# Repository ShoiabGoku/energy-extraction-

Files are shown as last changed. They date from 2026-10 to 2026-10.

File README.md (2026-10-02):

# Energy extraction from electric eels, used for the right purposes

A machine design with **animated 3D models** that open in any 3D program, plus the engineering behind them.

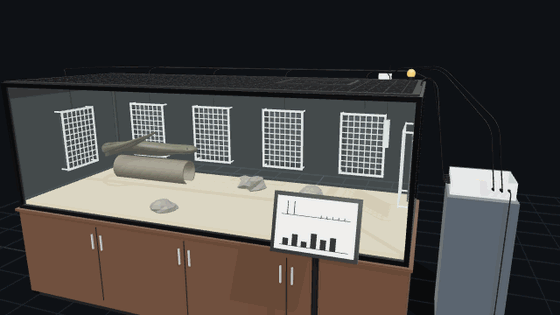
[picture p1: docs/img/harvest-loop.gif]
The eel swims, strikes its food, and the energy flows from two wall plates into the harvester


An electric eel can fire up to **860 V**, but each pulse lasts only about **2 ms**. Wall electrodes in its tank collect about **0.1 J a day**, so one eel would need about a thousand years to charge a phone. Taking more would mean provoking the animal, and that is cruel. The design therefore has two parts:

| | Part A: passive habitat harvester | Part B: artificial electric organ |
|---|---|---|
| Idea | Collect only the pulses the eel fires anyway | Copy the eel's cells in hydrogel instead of using the eel |
| Output | Microwatts, event-driven | Volts from salt gradients, scalable |
| Used for | Keeper shock alarm, eel health log, education display | Implants without battery-replacement surgery, soft robots, blue energy |
| Model | [`models/eel-habitat-harvester.*`](models) | [`models/artificial-electric-organ.*`](models) |

Read the full design, with the energy derivations, electronics, bill of materials, welfare rules and references, in **[docs/DESIGN.md](docs/DESIGN.md)**.

System diagram

## What the animation shows

The habitat model holds one **28.8-second loop** that packs a day's highlights together. The eel swims a path around the tank. Its body follows its head, it ripples with a travelling wave, and it rises to gulp air, as electric eels must. At three moments it fires, and each discharge is computed, not just drawn:

| Time | What the eel does | Plates that conduct | ΔV between them | Energy collected per pulse |
|---|---|---|---|---|
| 1.8 s | Probing doublet over the hide (2 pulses) | E2 + / E6 − | 26 V | 1.3 mJ |
| 7.7 s | Feeding strike: 70-pulse volley in two bursts | E5 + / E2 − | 71 V | 10.2 mJ |
| 27.1 s | Probing doublet near the end wall (2 pulses) | E1 + / E6 − | 51 V | 5.2 mJ |

The weak ~10 V sensing pulses it fires while cruising give only 0.7 V at the plates. That is below the bridge's 1.4 V diode drop, so they can't be harvested at all.

For every discharge you can watch the energy's path:

1. The **field lines** flash from the eel's head (+) to its tail (−).
2. The **conducting pair of plates** glows: red for +, blue for −.
3. **Energy dots** run along the two live leads into the harvester. Real current is instant; the dots are slowed so you can follow them.
4. The **bridge, catch capacitor, converter and supercapacitor** light up in turn.
5. The **alarm beacon** flashes, the **monitor LED** logs the event, and after the feeding strike the **e-paper display** refreshes with the new waveform.

The physics behind each frame comes from the same code that builds the model. The eel is treated as a head/tail current dipole in water of conductivity 0.01 S/m, and the six insulating tank walls are modelled as mirrors (the method of images). That gives each plate's voltage and, from those, the matched-load energy. All of it is saved in [`models/eel-habitat-harvester.timeline.json`](models/eel-habitat-harvester.timeline.json).

Part B animates too: Na⁺ ions cross the cation membrane one way and Cl⁻ ions cross the anion membrane the other way, together making one current.

## The viewer and its panels

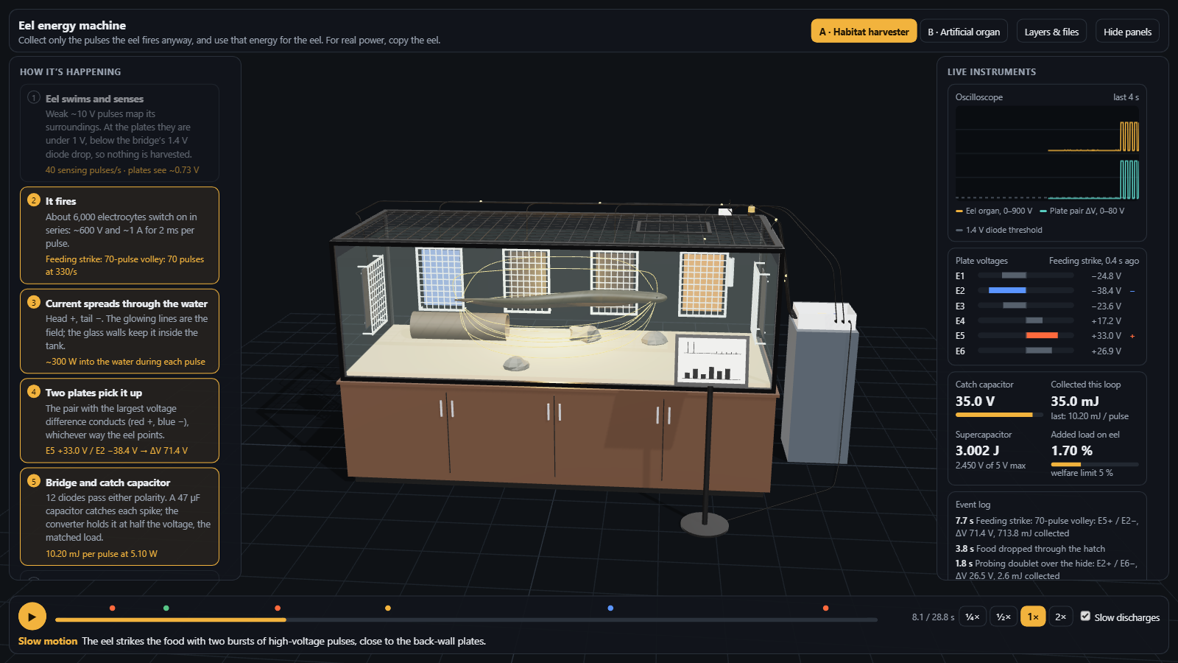
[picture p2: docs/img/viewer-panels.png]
Viewer with the step and instrument panels during the feeding strike


Open `index.html` through any static server, or enable GitHub Pages for this repo. The viewer has:

- **How it's happening.** Seven steps, from "Eel swims and senses" to "Put to the right use". Each one lights up while it is happening, with live numbers such as the conducting plates, ΔV, energy per pulse and energy stored.
- **Live instruments.** An oscilloscope of the eel's voltage and the plate-pair ΔV against the 1.4 V diode threshold. Voltage bars for all six plates with the + and − pair marked. Gauges for the catch capacitor and supercapacitor, the energy collected this loop, and the added load on the eel against the 5% welfare limit. An event log.
- **Transport.** Play/pause, a scrubber with event markers, speeds from ¼× to 2×, and automatic slow motion during discharges. A caption narrates what is happening.
- **Part B panels.** A five-step explanation of the gel battery and a stack calculator: drag the number of cells and see the voltage and stack length.
- **Hover any part** to read its description. Use **Layers & files** to toggle parts and download any format.

## 3D models

Each model is exported in three formats so that anything can open it:

| File | Format | Opens in | Notes |
|---|---|---|---|
| `*.glb` | glTF 2.0 binary, **animated** | Blender, Unity, Unreal, Godot, three.js / Babylon.js, Windows 3D Viewer, KeyShot, online glTF viewers | Rigged eel (24-joint skin) and one looping clip with 100 channels: swimming, field flashes, plate glows, energy dots, harvester stages, beacon, display, food. PBR materials, named hierarchy, a description on every part (`extras.description`). Passes the Khronos glTF Validator with 0 errors, 0 warnings, 0 hints |
| `*.obj` + `*.mtl` | Wavefront OBJ | Practically every 3D program: Maya, 3ds Max, Cinema 4D, SketchUp, Rhino, MeshLab… | One frozen moment, mid feeding strike. One named object per part with colours, emission and opacity |
| `*.stl` | Binary STL | Slicers (Cura, PrusaSlicer), CAD (Fusion, SolidWorks, FreeCAD), and **GitHub's built-in 3D preview** (click the file) | The same frozen moment. Single colour, **millimetres, +Z up**, opaque parts only (glass, water, field lines and glows left out so you can see inside) |

GLB and OBJ use **metres, +Y up**. The habitat model is 3.7 × 1.9 × 1.9 m including the pedestal and display. The organ model is 380 × 200 × 87 mm. In renderers that don't play animation, the GLB shows the same frozen moment as the OBJ.

| Eel and its discharge field | Energy reaching the harvester |
|---|---|
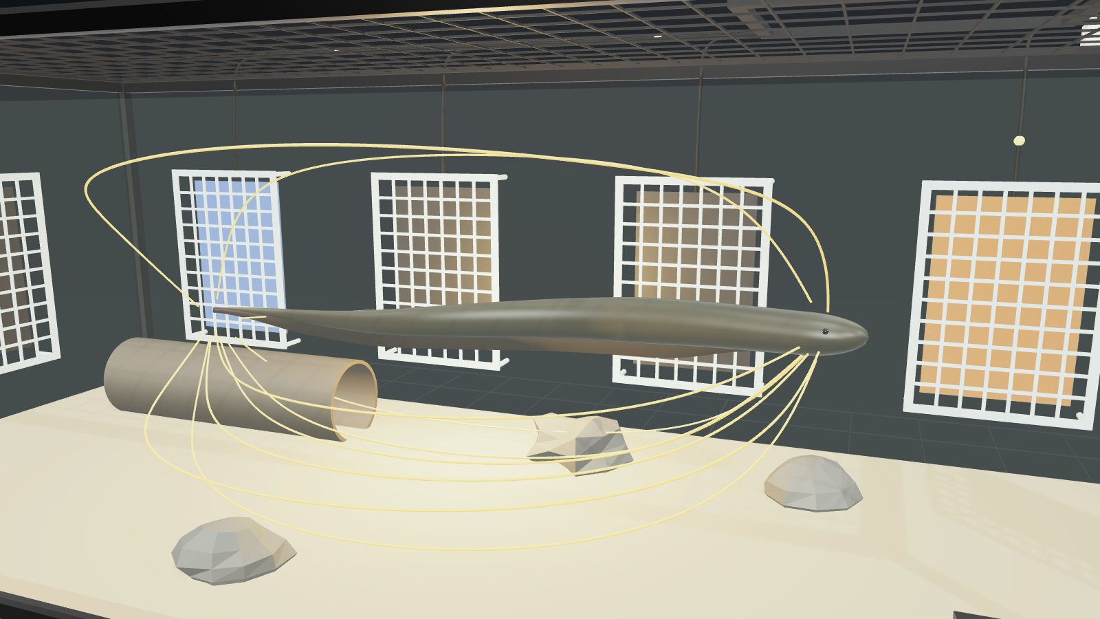
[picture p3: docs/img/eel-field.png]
Eel and discharge field
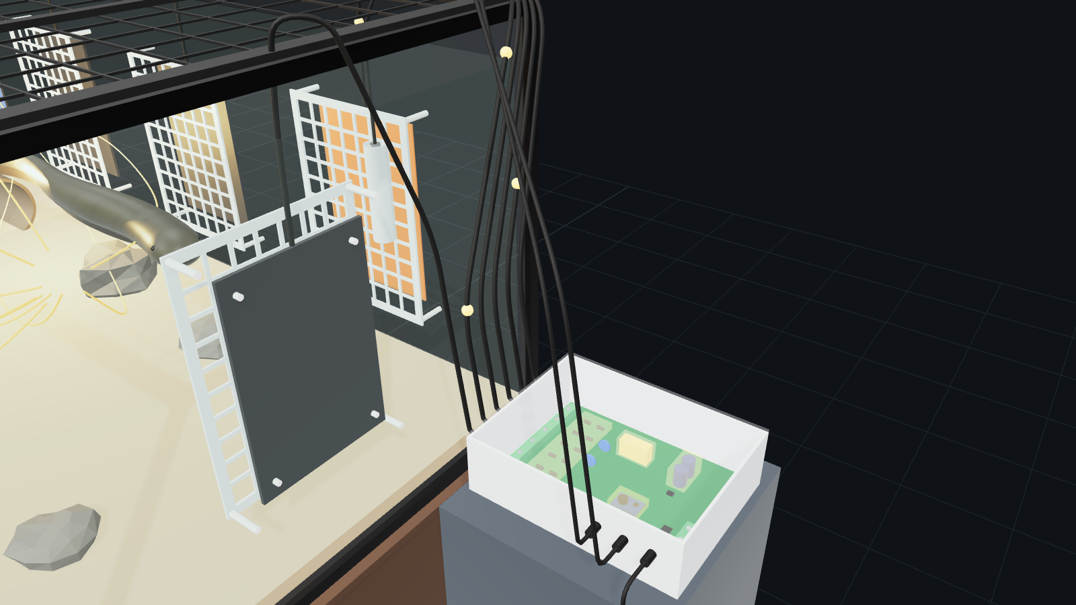
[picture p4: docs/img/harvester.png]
Harvester electronics
|  |  |
| **Whole habitat** | **Part B: artificial electric organ** |
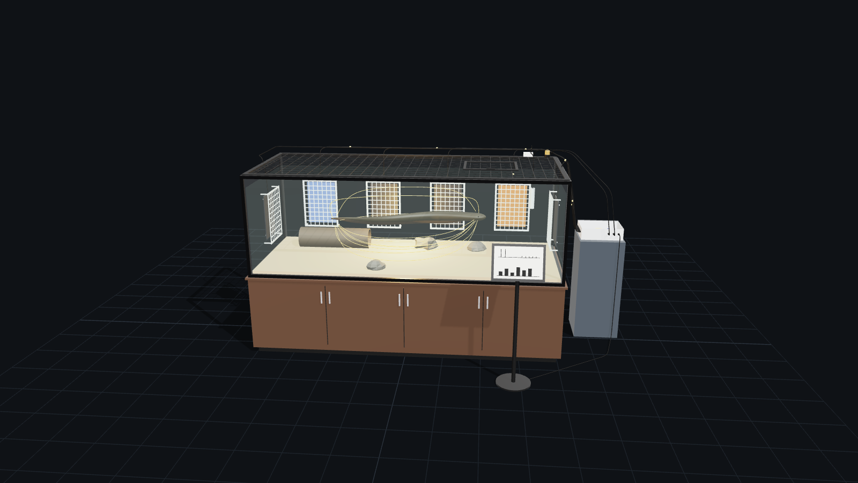
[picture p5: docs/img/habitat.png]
Habitat
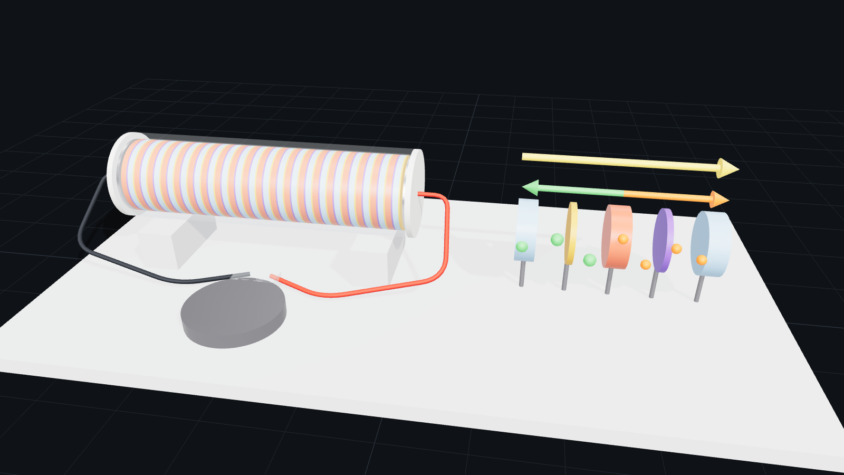
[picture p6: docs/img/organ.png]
Organ
|  |  |

### Quick start

- **Blender:** File → Import → glTF 2.0 → `models/eel-habitat-harvester.glb`, then press play in the Timeline. The water and glass are transparent; the field lines, plate glows and beacon glow.
- **Windows:** double-click the `.glb` file. 3D Viewer plays the animation.
- **Unity / Unreal / Godot:** import the `.glb` and play its one clip, "Swim and harvest (loop)".
- **Browser:** run `python -m http.server` in this folder and open `http://localhost:8000`.
- **Print or CAD:** use the `.stl` file.

## Regenerating the models

The models, the animation and the timeline are all generated from code. Every dimension, the swimming path and the electrical constants in [`tools/build_models.py`](tools/build_models.py) can be changed and rebuilt:

```bash
pip install numpy
python tools/build_models.py
```

The output is deterministic, so the same code always produces the same files.

## The rules built into this machine

1. **Passive only.** No prodding, baiting, stimulation, or feeding schedules changed to make the eel fire more.
2. **No added effort for the eel.** The harvester may add at most 5% to the eel's load. It adds about 0.1–0.5% mid-tank and up to ~2% when the eel fires right beside a plate.
3. **Welfare comes before output.** The health monitor runs on its own battery, so it never goes dark when a sick eel discharges less.
4. **No surgery, implants or restraint.** Only captive-bred or rescued eels in accredited facilities.
5. **No weapons or stunning devices.** The 3.3 V-only output and small energy store make that a hardware limit.

Energy figures are order-of-magnitude estimates with their assumptions stated in [DESIGN.md](docs/DESIGN.md). They should be refined with measurements from a real habitat.

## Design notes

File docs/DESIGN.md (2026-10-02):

# Design: an electric-eel energy machine used for the right purposes

This document is the engineering design behind the 3D models in [`../models`](../models).
It has two parts:

- **Part A, the passive habitat harvester.** It collects a small share of the pulses an electric eel fires anyway, and spends that energy on keeper safety and teaching. It never stimulates the animal.
- **Part B, the artificial electric organ.** It copies the eel's electrocytes in hydrogel. This is the only route to useful amounts of power, and it needs no animal.

The numbers below are estimates accurate to about a factor of ten. Each one shows its assumption so it can be checked against real measurements.

---

## 1. The constraint that shapes everything

An electric eel's discharge is powerful but brief. One high-voltage pulse reaches hundreds of volts, but lasts only about 2 ms. Most of its energy heats the water right next to the eel. Getting a lot of energy out of an eel would mean provoking it to fire again and again. That is cruel, and the arithmetic below shows it still wouldn't give useful power.

So the design rule is: **collect passively, spend the energy on the eel's keepers and visitors, and get real power from biomimicry (copying how the eel works), not from the animal.**

## 2. The source

| Property | Value | Source / note |
|---|---|---|
| Electrocytes | ~6,000 in series, ~0.15 V each | Cells stacked along the body, like batteries in a torch |
| Peak organ voltage | up to 860 V (*E. voltai*); ~500–600 V other species | de Santana et al., 2019 |
| Pulse width | ~2 ms | High-voltage discharge |
| Volleys | up to ~400 pulses/s while hunting | Catania, 2014 |
| Polarity | head positive, tail negative | |
| Internal resistance, R_i | ~300 Ω (assumed) | To be measured during commissioning |

**Pulse energy.** Treat the eel as a voltage source V_e behind R_i, driving into the water.
The water's resistance between the head and tail regions is roughly that of two small electrodes in a large bath:

```
R_water ≈ (1 / 2πσ) · (1/a − 1/d)        a ≈ 0.05 m, d ≈ 1.5 m, σ ≈ 0.01 S/m (100 µS/cm)
        ≈ 300 Ω
I       ≈ V_e / (R_i + R_water) ≈ 600 / 600 ≈ 1 A
P_water ≈ I² · R_water ≈ 300 W   for ~2 ms   →   E_pulse ≈ 0.6 J   (range 0.1–1 J)
```

## 3. What the wall plates can actually collect

Away from the eel, the water carries the potential field of a current dipole:

```
φ(r) = (I / 4πσ) · (1/r₊ − 1/r₋)          I / 4πσ ≈ 8 V·m
```

With the eel mid-tank, a back-wall plate sits about 0.6 m from the head and 1.5 m from the tail.
The insulating glass walls roughly double the potential, since current can't leave the water.
Typical plate-to-plate differences come out at **10–30 V**. They are higher when the eel swims right past a plate.

Each 300 × 450 mm plate has a spreading resistance into the water of about 1/(4σa) ≈ 120 Ω, where a ≈ 0.21 m is the plate's equivalent radius. A pair therefore looks like a ~20 V source behind ~240 Ω. Even with a perfectly matched load:

```
P_harvest = ΔV² / 4R ≈ 20² / 960 ≈ 0.4 W   for 2 ms   →   ≈ 1 mJ per pulse   (≈ 0.2–10 mJ)
```

That is about **0.1–1%** of what the eel puts into the water.

### Daily energy budget (one adult eel)

| Step | Typical | Range |
|---|---|---|
| High-voltage pulses per day in captivity (feeding volleys, startles, probing) | 200 | 50–1,000 |
| Energy collected per pulse | 1 mJ | 0.2–10 mJ |
| Converter efficiency (bursty, high-voltage input) | 70% | 60–75% |
| **Collected per day** | **~0.14 J** | ~0.01–7 J |
| **Average power** | **~1.6 µW** | ~0.1–80 µW |

For scale, a phone charge is about 15 Wh, or 54 kJ. At the typical rate, one eel would need **about a thousand years** to charge one phone.

> An earlier back-of-envelope version of this design assumed 1–5% capture. The dipole and spreading-resistance analysis above lowers that by roughly 10×. The design has been changed to match (see §4.5).

### Extra effort for the eel: negligible by design

Mid-tank, the harvester draws about 0.4–0.7 W, briefly, from a ~300 W pulse, so it adds about 0.1–0.2% to the eel's load. When the eel fires right beside a plate it can reach ~5 W, about 2%. The welfare rule (§5) caps this at 5%, and a commissioning test checks it (§4.7).

## 4. Part A: passive habitat harvester

Habitat harvester

### 4.1 Habitat (welfare comes first)

| Item | Spec |
|---|---|
| Tank | 3.0 × 1.2 × 1.0 m outside, 19 mm glass, about 2,900 L of water |
| Water | Soft and warm, at species-appropriate values set by the keeper or vet. Surface 12 cm below the rim: electric eels gulp air and must reach it |
| Lid | Escape-proof mesh with a feeding hatch |
| Furnishing | Dark hide tube (Ø220 mm), rocks, sand substrate |
| Stand | 0.8 m cabinet; mains equipment (heater, pump) on a 30 mA RCD/GFCI |

### 4.2 Electrode array

- **Six graphite plates,** 300 × 450 × 8 mm: one on each end wall (E1, E6) and four on the back wall (E2–E5), centred at mid-depth. Graphite is inert. Copper, zinc and brass are never used, because their ions are toxic to fish.
- **Guard screens:** perforated acrylic grids 75 mm from the glass, with ~40 mm openings, so the eel can never touch an electrode.
- **Wiring:** each plate has one silicone-insulated lead. The joint is potted in epoxy, so the only conductor touching the water is the graphite face.
- **Why six plates:** the eel's head-to-tail axis changes every time it turns. With six plates, some pair always lies roughly along that axis.

### 4.3 Pulse catcher

```
 E1 ─┬─▶|─┐                          ┌──────────────┐
     └─|◀─┼─┐      + rail ───┬───────┤ buck, MPPT   ├──▶ low-leakage supercap ──▶ 3.3 V loads
 E2 ─┬─▶|─┘ │                │       │ in 6–150 V   │
     └─|◀───┤   (×6 plates)  ═╪═ 47 µF  wake ≥ 10 V  │
  …         │                │ 250 V └──────────────┘
 E6 ─┬─▶|─  │      MOV+TVS ──┤ 150 V
     └─|◀───┴──── − rail ────┘
```

- **Six-input polyphase diode bridge** (12 diodes, ≥1 kV). Each plate has one diode to the + rail and one to the − rail. The rails therefore always carry the largest plate-to-plate difference, whatever the polarity and whichever two plates see it. No switching logic is needed.
- **Clamp:** a varistor (MOV) plus a TVS diode at ~150 V, for the rare pulse when the eel touches a guard right next to a plate.
- **Catch capacitor:** 47 µF / 250 V film. It smooths each 2 ms spike. Its time constant with the ~240 Ω plate source is about 11 ms, so charge builds up across a volley.
- **Converter:** a buck converter accepting 6–150 V input, ~5 W peak. A feeding volley fired beside a plate averages ~3.4 W for a fraction of a second; anything above the rating is shed by the clamp. It wakes when the capacitor reaches 10 V and then runs *fractional open-circuit MPPT* (maximum power point tracking): it holds its input at about half the open-circuit plate voltage. That is the matched load from §3 that extracts the most energy from each pulse. It sleeps again between volleys, drawing well under 1 µW.
- Note that the catch capacitor can never charge above the plate voltage. A start threshold set higher than typical pulses (10–30 V) would never fire, which is why the wake threshold is low.

### 4.4 Storage: the leakage trap

A good-quality 1 F supercapacitor at 5 V leaks a few microwatts on its own. That is about as much as the eel delivers on a typical day, so long-term storage would mostly store nothing. The design therefore **spends energy where it is caught:**

1. A volley charges the catch capacitor.
2. That charge flashes the alarm beacon directly and wakes the logger to record the event.
3. Only on unusually active days does the surplus top up the supercapacitor bank: 2 × 2 F / 2.7 V low-leakage cells in series, giving 1 F and 12.5 J at most. That bank feeds the display.
4. The output is **3.3 V only**, by hardware design, so it can never be turned into a shocking device.

### 4.5 Loads: the right purposes

| Load | What it does | Power | Powered by |
|---|---|---|---|
| **Keeper shock alarm** | Amber beacon on the lid by the feeding hatch flashes after every high-voltage volley | ~3 mJ per 50 ms flash, ~0.1 J per event | **The volley itself**, through the catch capacitor. The shock powers its own warning |
| **Eel health monitor** | Logs water temperature, conductivity and every discharge (count, amplitude, timing). Alerts keepers by Bluetooth LE | ~25 µW average | **Its own 10-year lithium cell**; harvested energy only tops it up |
| **Education display** | Large e-paper panel: energy collected today, the last pulse waveform, "years to charge a phone" | Holds its image at zero power; ~0.1–0.5 J per refresh | **Surplus only.** It refreshes when the eel has made enough, and the waiting is part of the lesson |

Two deliberate decisions:

- **The health monitor does not depend on the eel's energy.** A sick or stressed eel may discharge less, which is exactly when monitoring matters most. An eel-powered monitor would go dark at the worst moment.
- **Beacon on means the water is definitely live. Beacon off does not mean it is safe.** Keepers always follow the insulated-glove protocol.

**What the plates are best at is information, not energy.** The discharge record is a continuous, non-invasive behaviour log. Feeding strikes, probing doublets, startles, and long quiet periods (possible illness) all show up in it.

Monitor alert rules (starting points for the vet to tune):

- High-voltage volleys outside feeding times above a set hourly rate → possible stress.
- Discharge activity down more than 50% over 24 h → check health.
- Temperature or conductivity outside the set band → water-quality alert.

### 4.6 Bill of materials

| Qty | Part | Spec |
|---|---|---|
| 1 | Glass tank + cabinet + mesh lid | 3.0 × 1.2 × 1.0 m, 19 mm glass |
| 6 | Graphite electrode plates | 300 × 450 × 8 mm |
| 6 | Acrylic guard screens + PVC standoffs | 380 × 530 mm, 75 mm stand-off |
| 6 | Silicone-insulated leads, epoxy-potted joints | ~5 m each |
| 12 | Diodes | ≥1 kV, fast recovery |
| 1 | MOV + TVS clamp | ~150 V |
| 1 | Film capacitor | 47 µF / 250 V |
| 1 | High-voltage-input buck converter | hysteretic start, ~2 W |
| 2 | Supercapacitors, low leakage | 2 F / 2.7 V, in series |
| 1 | Low-power MCU + Bluetooth LE radio | |
| 1 | Temperature + conductivity probe, in a guard tube | |
| 1 | Lithium primary cell for the monitor | AA Li-SOCl₂ |
| 1 | Amber LED beacon | |
| 1 | Large e-paper display on a stand | |
| 1 | IP-rated enclosure with clear lid, 9 cable glands, steel pedestal | |

### 4.7 Commissioning tests

1. **Loading test (welfare).** With a separate high-impedance probe pair (≥10 MΩ), record the eel's pulse amplitude with the harvester connected and disconnected. The difference must be under 5%. If it isn't, add series resistance per plate or remove plates.
2. **No DC into the water.** With no eel present, measure the current through every plate lead. It must be zero within instrument resolution.
3. **Isolation.** The harvester floats: no connection to mains earth. Check insulation from every lead to the enclosure at 1 kV.
4. **Field calibration.** Log a week of plate voltages, then refine the energy budget in §3 with real numbers.

### 4.8 Simulated discharges (what the animation shows)

`tools/build_models.py` turns this section into numbers for every discharge in the animated model:

- **Eel.** A 1.65 m rig with 24 joints follows a closed swimming path at ~0.18 m/s. It speeds up to strike and slows to surface. A travelling body wave runs faster than the eel swims.
- **Field.** The eel is a current dipole: +1 A at the head end of the organ, −1 A at the tail, in water with σ = 0.01 S/m. The four glass walls, the floor and the water surface are insulating, so each source is mirrored in all six (first-order method of images).
- **Plates.** Each plate's voltage is the field's potential averaged over a 5 × 5 grid on its face. The bridge conducts the most-positive and most-negative plates. The energy per pulse is (ΔV − 1.4 V)² / (4 × 240 Ω) × 2 ms.

| Discharge | Eel position | Conducting pair | ΔV | Per pulse | Pulses | Collected | Added load |
|---|---|---|---|---|---|---|---|
| Probing doublet | over the hide, mid-tank | E2 + / E6 − | 26.5 V | 1.3 mJ | 2 | 2.6 mJ | 0.2% |
| Feeding strike | beside the back-wall plates | E5 + / E2 − | 71.4 V | 10.2 mJ | 70 | 714 mJ | 1.7% |
| Probing doublet | head near end wall E1 | E1 + / E6 − | 51.2 V | 5.2 mJ | 2 | 10.3 mJ | 0.9% |
| Sensing pulses (~10 V) | cruising | none | 0.7 V | 0 | — | 0 | 0% |

The table shows how much **position** matters. The same eel collects about 8× more per pulse when it fires beside a plate than when it fires mid-tank. A feeding strike right beside the plates, as in this example, is close to the best case. A typical day, with most pulses mid-tank, stays around 0.1 J. The animation also stretches each 2 ms pulse into a visible flash and slows the energy dots in the leads; the numbers above use the real timings.

## 5. Rules built into the machine

These are requirements the design must meet, not suggestions:

1. **Passive only.** No prodding, baiting, electrical stimulation, or feeding schedules changed to make the eel fire more. The machine never tries to increase its output.
2. **No added effort for the eel.** The harvester may add at most 5% to the eel's load (checked by test 4.7-1). Typically it adds ~0.1%.
3. **Welfare comes before output.** Discharge patterns that suggest stress raise an alert. Nothing in the system rewards "more energy".
4. **No surgery, implants or restraint.**
5. **Only captive-bred or rescued eels** in accredited facilities. No wild capture for energy.
6. **No weapons or stunning devices.** The low-voltage-only output and small energy store make this a hardware limit, not just a policy.

## 6. Part B: artificial electric organ

Artificial electric organ

The eel's trick is a stack of cells, each making ~0.15 V from a salt (ion) gradient. Hydrogels can do the same:

```
… | low-salt | anion-selective | HIGH-SALT | cation-selective | low-salt | …
           ◀── Cl⁻                            Na⁺ ──▶
                       conventional current ──▶  (+x end is +)
```

- Positive ions (Na⁺) leave the high-salt gel through the cation-selective membrane, toward +x.
- Negative ions (Cl⁻) leave through the anion-selective membrane the other way.
- Both flows add up to one current in the same direction. Each four-layer cell gives roughly 0.13–0.18 V.
- Schroeder et al. (2017) stacked 2,449 gel compartments (≈612 cells) to reach **110 V** open circuit.

The model shows a **20-cell stack** (≈3–3.6 V open circuit) in a soft silicone sleeve:

| Item | Spec in the model |
|---|---|
| High-salt gel / low-salt gel | Ø40 mm × 3 mm each |
| Cation- / anion-selective membranes | Ø40 mm × 0.8 mm each |
| Cell (4 layers) | 7.6 mm; 20 cells = 152 mm |
| Electrodes | Ag/AgCl discs at both ends, which turn ion current into electron current |
| Load | Implant (pacemaker-style titanium can) |

**Right purposes for Part B:**

- **Implants powered by the body.** Pacemakers, glucose sensors and nerve stimulators could run on the body's own ion gradients, so the battery never needs replacing by surgery. This is the goal Schroeder et al. aimed at.
- **Soft robots and wearables** that bend without cracking a battery.
- **Blue energy.** The same membrane physics at river mouths, where fresh water meets the sea, is called reverse electrodialysis. Pilot plants exist, such as REDstack on the Afsluitdijk in the Netherlands. At that scale the principle produces real power.

## 7. What this machine must never be used for

- Shocking, stunning, deterring or harming people or animals.
- "Eel farms" or any setup that keeps eels for their energy.
- Stimulating eels to discharge more, for energy, display or entertainment.

## 8. References

- de Santana, C. D. et al. (2019). *Unexpected species diversity in electric eels with a description of the strongest living bioelectricity generator.* Nature Communications 10, 4000.
- Catania, K. C. (2014). *The shocking predatory strike of the electric eel.* Science 346, 1231–1234.
- Catania, K. C. (2016). *Leaping eels electrify threats, supporting Humboldt's account of a battle with horses.* PNAS 113, 6979–6984.
- Catania, K. C. (2017). *Power transfer to a human during an electric eel's shocking leap.* Current Biology 27, 2887–2891.
- Schroeder, T. B. H. et al. (2017). *An electric-eel-inspired soft power source from stacked hydrogels.* Nature 552, 214–218.
- Xu, J. & Lavan, D. A. (2008). *Designing artificial cells to harness the biological ion concentration gradient.* Nature Nanotechnology 3, 666–670.

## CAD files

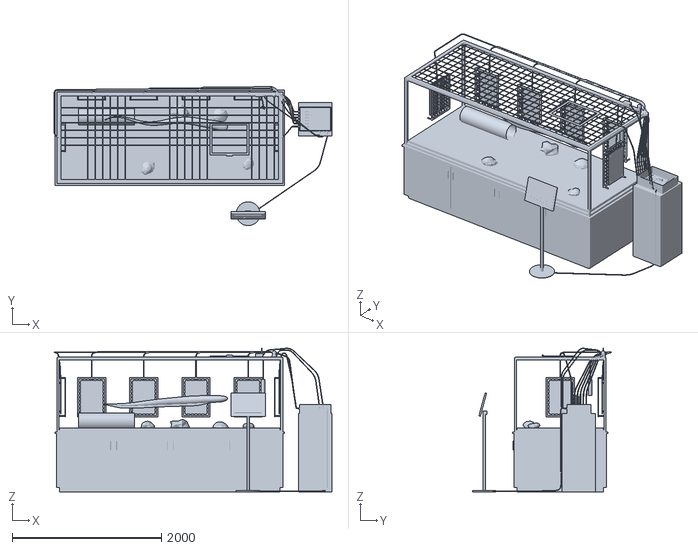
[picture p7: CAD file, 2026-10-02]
models/eel-habitat-harvester.stl
3729.4 x 1868.5 x 1927.9

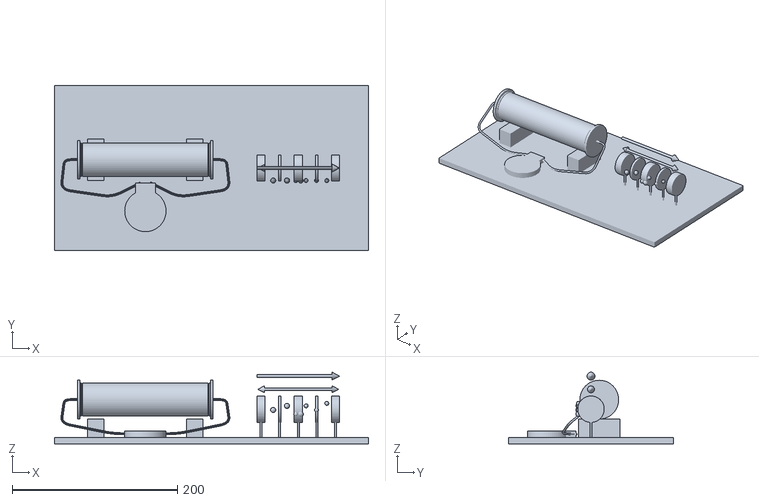
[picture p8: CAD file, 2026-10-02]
models/artificial-electric-organ.stl
380.0 x 200.0 x 86.8

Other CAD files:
models/artificial-electric-organ.obj
models/eel-habitat-harvester.obj

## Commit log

2026-10-02 Add eel energy machine design with 3D models
    Passive electric-eel habitat harvester (Part A) and an eel-inspired
    hydrogel artificial electric organ (Part B), generated procedurally by
    tools/build_models.py and exported as GLB (glTF 2.0), OBJ+MTL and STL.
    - GLB passes the Khronos glTF Validator with 0 errors/warnings
    - Every part carries a description in glTF extras
    - index.html: three.js viewer with layers, hover info, PNG export
    - docs/DESIGN.md: energy derivation, electronics, BOM, welfare rules
    [artificial-electric-organ.obj, artificial-electric-organ.stl, eel-habitat-harvester.obj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]
2026-10-02 Animate the eel and the energy flow; add live explanation panels
    - Rigged 24-joint eel swims a closed loop (follow-the-leader body,
    travelling wave, surfacing to breathe) as a glTF skin + animation
    - Every discharge is computed: head/tail current dipole with the six
    insulating tank boundaries as image sources gives each plate's
    voltage, the conducting pair and the matched-load energy
    - Animated field-line flashes, plate glows, energy dots along the live
    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
    [artificial-electric-organ.obj, artificial-electric-organ.stl, eel-habitat-harvester.obj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]
2026-10-14 Add realistic sound, synced to the animation
    Only sounds with a real source; the discharge itself is silent in water.
    - Tank: filter pump mains hum, flowing water, Minnaert bubbles, food
    splash, the eel's surface gulp and dive bubbles, suction-strike thud
    - Exhibit speaker (new part on the display stand): the plate signal
    through a bio-amplifier - sensing clicks, doublet clicks, a ~330/s
    volley buzz, louder when the eel fires nearer a plate; mains powered
    - Alarm: piezo chirps with the beacon; flash/chirp count (2-12) now
    scales with the energy each discharge delivered
    - Synthesised by tools/build_models.py from the same event timeline:
    3-channel stems for the viewer, a stereo loop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
2026-10-15 Add the option of 1, 2 or 3 eels
    - Three rigged eels in one GLB with clips "1 eel", "2 eels", "3 eels"
    that share the swimming tracks; every animated node is keyed in every
    clip so switching is deterministic in any renderer
    - Eel B (1.35 m, ~490 V) swims the lower layer the other way round and
    rises through the middle to breathe; eel C (1.10 m juvenile, ~400 V)
    keeps to the upper layer at the back. Voltage and current scale with
    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
